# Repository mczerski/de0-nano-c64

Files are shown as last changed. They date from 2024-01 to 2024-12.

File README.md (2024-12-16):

# DE0-Nano expansion board for Commodore 64

This board adds necessary interfaces for Commodore 64 implementation from [this](https://github.com/mczerski/c64_DeMiSTify) project.

# Photos

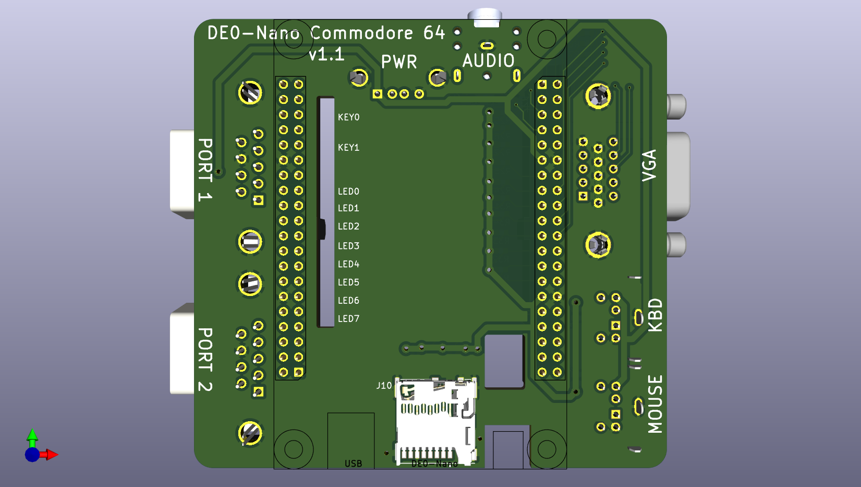
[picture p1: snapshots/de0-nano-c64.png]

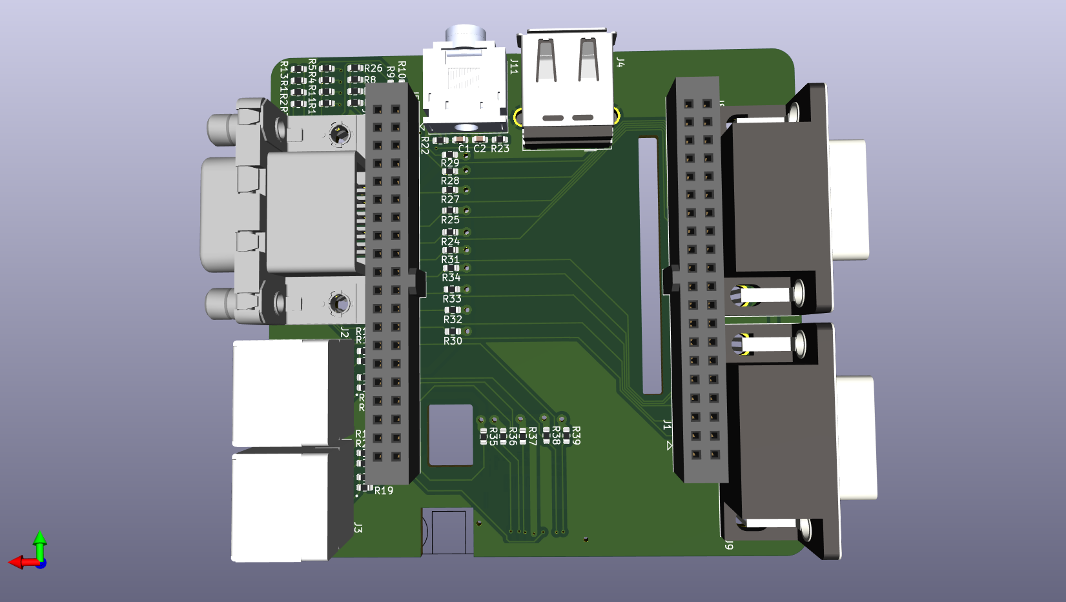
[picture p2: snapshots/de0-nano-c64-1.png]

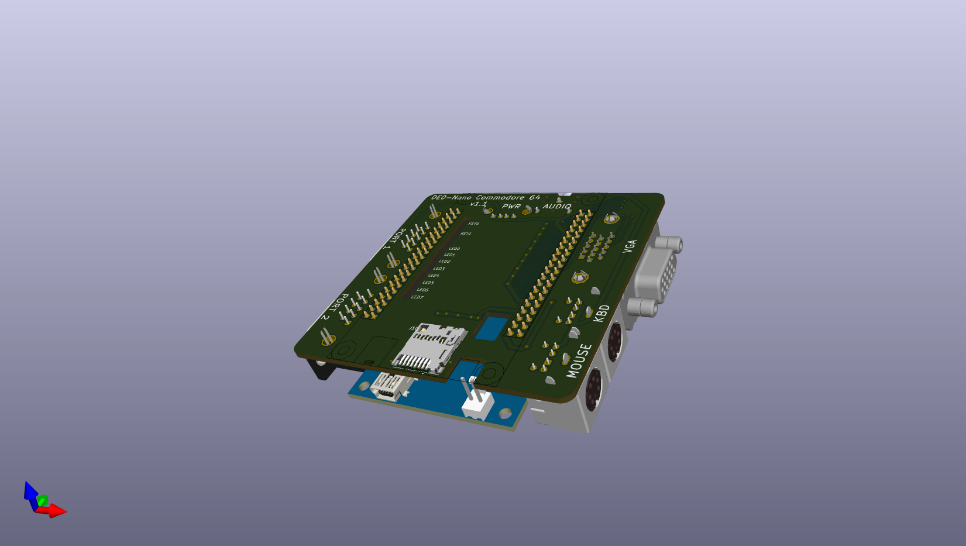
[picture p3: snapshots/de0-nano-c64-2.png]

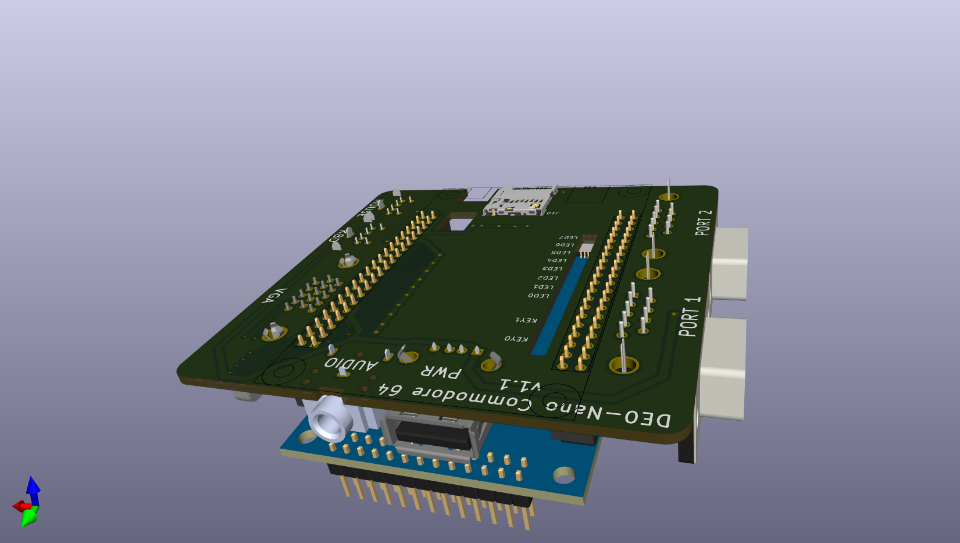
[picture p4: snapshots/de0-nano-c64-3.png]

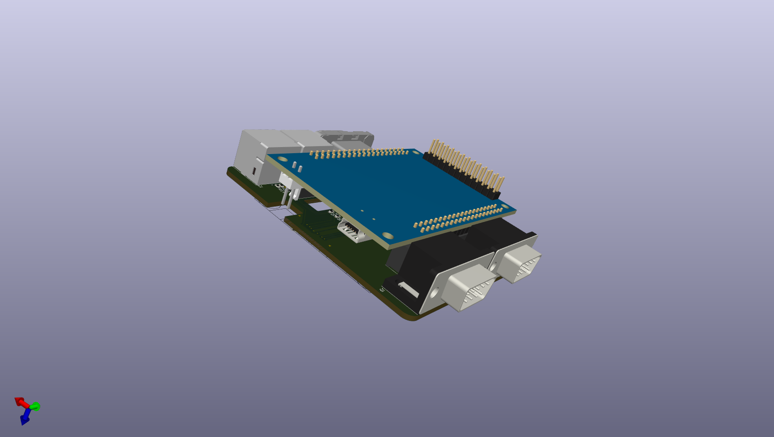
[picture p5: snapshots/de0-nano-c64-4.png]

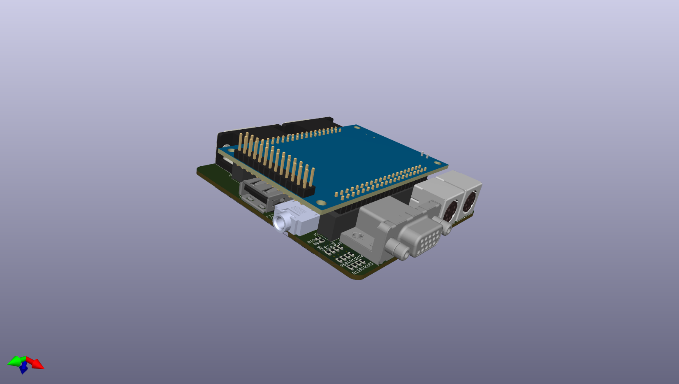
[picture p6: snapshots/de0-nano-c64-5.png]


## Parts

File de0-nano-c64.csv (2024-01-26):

Id | Oznaczenie | Footprint | Liczba | Oznaczenie | Dostawca i numer artykułu
1 | J10 | MOLEX_503398-1892 | 1 | SD_Card
2 | J6 | AMPHENOL_ICD15S13E4GV00LF | 1 | VGA
3 | C1,C2 | C_0603_1608Metric | 2 | 10n
4 | R1,R7,R11 | R_0603_1608Metric | 3 | 1k
5 | R2,R4,R8 | R_0603_1608Metric | 3 | 2k
6 | R3,R5,R26 | R_0603_1608Metric | 3 | 3.9K
7 | R6,R12,R13 | R_0603_1608Metric | 3 | 510
8 | R9,R10 | R_0603_1608Metric | 2 | 47
9 | R14,R15,R20,R21 | R_0603_1608Metric | 4 | 2K
10 | R16,R17,R18,R19 | R_0603_1608Metric | 4 | 120
11 | R22,R23 | R_0603_1608Metric | 2 | 4.7k
12 | R24,R25,R27,R28,R30,R31,R37,R32,R29,R34,R38,R35,R36,R33,R39 | R_0603_1608Metric | 15 | 10k
13 | J2 | CUI_MD-60S | 1 | PS2_0
14 | J1 | PinSocket_2x20_P2.54mm_Polarized_Vertical | 1 | GPIO_0
15 | J3 | CUI_MD-60S | 1 | PS2_1
16 | J5 | PinSocket_2x20_P2.54mm_Polarized_Vertical | 1 | GPIO_1
17 | J8 | DSUB-9_Male_Horizontal_P2.77x2.84mm_EdgePinOffset7.70mm_Housed_MountingHolesOffset9.12mm | 1 | JOYSTICK_1
18 | J11 | Jack_3.5mm_CUI_SJ1-3523N_Horizontal | 1 | AUDIO
19 | J9 | DSUB-9_Male_Horizontal_P2.77x2.84mm_EdgePinOffset7.70mm_Housed_MountingHolesOffset9.12mm | 1 | JOYSTICK_2

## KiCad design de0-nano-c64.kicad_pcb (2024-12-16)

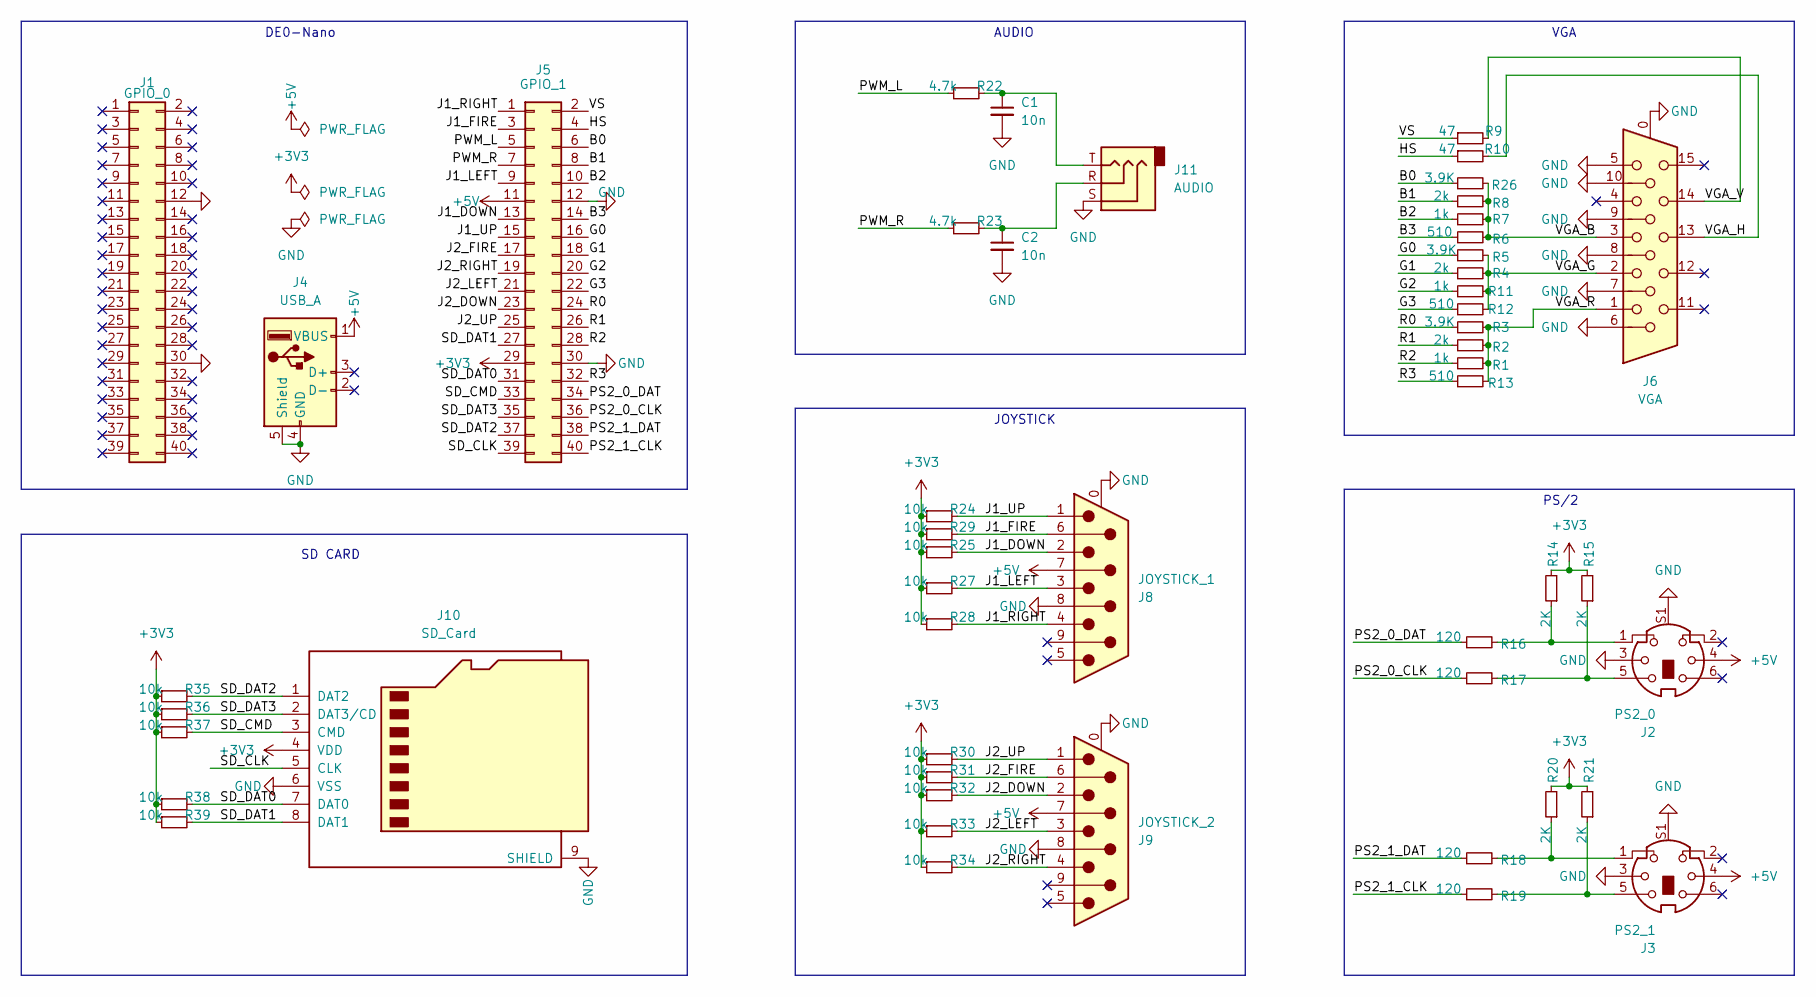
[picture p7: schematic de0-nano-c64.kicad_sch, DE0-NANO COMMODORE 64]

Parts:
C1, C2: 10n; C_0603_1608Metric
J1: GPIO_0; PinSocket_2x20_P2.54mm_Polarized_Vertical
J2: PS2_0; CUI_MD-60S
J3: PS2_1; CUI_MD-60S
J4: USB_A; USB_A_Molex_67643_Horizontal
J5: GPIO_1; PinSocket_2x20_P2.54mm_Polarized_Vertical
J6: VGA; AMPHENOL_ICD15S13E4GV00LF
J8: JOYSTICK_1; DSUB-9_Male_Horizontal_P2.77x2.84mm_EdgePinOffset7.70mm_Hou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
J9: JOYSTICK_2; DSUB-9_Male_Horizontal_P2.77x2.84mm_EdgePinOffset7.70mm_Hou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
J10: SD_Card; MOLEX_503398-1892
J11: AUDIO; Jack_3.5mm_CUI_SJ1-3523N_Horizontal
R1, R7, R11: 1k; R_0603_1608Metric
R2, R4, R8: 2k; R_0603_1608Metric
R3, R5, R26: 3.9K; R_0603_1608Metric
R6, R12, R13: 510; R_0603_1608Metric
R9, R10: 47; R_0603_1608Metric
R14, R15, R20, R21: 2K; R_0603_1608Metric
R16, R17, R18, R19: 120; R_0603_1608Metric
R22, R23: 4.7k; R_0603_1608Metric
R24, R25, R27, R28, R29, R30, R31, R32, R33, R34, R35, R36, R37, R38, R39: 10k; R_0603_1608Metric

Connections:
+3V3: J5.29, J10.4 (VDD), R14.2, R15.2, R20.2, R21.2, R24.1, R25.1, R27.1, R28.1, R29.1, R30.1, R31.1, R32.1, R33.1, R34.1, R35.1, R36.1, R37.1, R38.1, R39.1
+5V: J2.4, J3.4, J4.1 (VBUS), J5.11, J8.7, J9.7
/B0: J5.6, R26.1
/B1: J5.8, R8.1
/B2: J5.10, R7.1
/B3: J5.14, R6.1
/G0: J5.16, R5.1
/G1: J5.18, R4.1
/G2: J5.20, R11.1
/G3: J5.22, R12.1
/HS: J5.4, R10.1
/J1_DOWN: J5.13, J8.2, R25.2
/J1_FIRE: J5.3, J8.6, R29.2
/J1_LEFT: J5.9, J8.3, R27.2
/J1_RIGHT: J5.1, J8.4, R28.2
/J1_UP: J5.15, J8.1, R24.2
/J2_DOWN: J5.23, J9.2, R32.2
/J2_FIRE: J5.17, J9.6, R31.2
/J2_LEFT: J5.21, J9.3, R33.2
/J2_RIGHT: J5.19, J9.4, R34.2
/J2_UP: J5.25, J9.1, R30.2
/PS2_0_CLK: J5.36, R17.1
/PS2_0_DAT: J5.34, R16.1
/PS2_1_CLK: J5.40, R19.1
/PS2_1_DAT: J5.38, R18.1
/PWM_L: J5.5, R22.1
/PWM_R: J5.7, R23.1
/R0: J5.24, R3.1
/R1: J5.26, R2.1
/R2: J5.28, R1.1
/R3: J5.32, R13.1
/SD_CLK: J5.39, J10.5 (CLK)
/SD_CMD: J5.33, J10.3 (CMD), R37.2
/SD_DAT0: J5.31, J10.7 (DAT0), R38.2
/SD_DAT1: J5.27, J10.8 (DAT1), R39.2
/SD_DAT2: J5.37, J10.1 (DAT2), R35.2
/SD_DAT3: J5.35, J10.2 (DAT3/CD), R36.2
/VGA_B: J6.3, R6.2, R7.2, R8.2, R26.2
/VGA_G: J6.2, R4.2, R5.2, R11.2, R12.2
/VGA_H: J6.13, R10.2
/VGA_R: J6.1, R1.2, R2.2, R3.2, R13.2
/VGA_V: J6.14, R9.2
/VS: J5.2, R9.1
GND: C1.2, C2.2, J1.12, J1.30, J2.3, J2.S1, J3.3, J3.S1, J4.4 (GND), J4.5 (Shield), J5.12, J5.30, J6.0, J6.5, J6.6, J6.7, J6.8, J6.9, J6.10, J8.0 (PAD), J8.8, J9.0 (PAD), J9.8, J10.6 (VSS), J10.9 (SHIELD), J11.S
unnamed: C1.1, J11.T, R22.2
unnamed: C2.1, J11.R, R23.2
unnamed: J2.1, R14.1, R16.2
unnamed: J2.5, R15.1, R17.2
unnamed: J3.1, R18.2, R20.1
unnamed: J3.5, R19.2, R21.1

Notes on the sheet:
VGA
JOYSTICK
SD CARD
PS/2
DE0-Nano
AUDIO

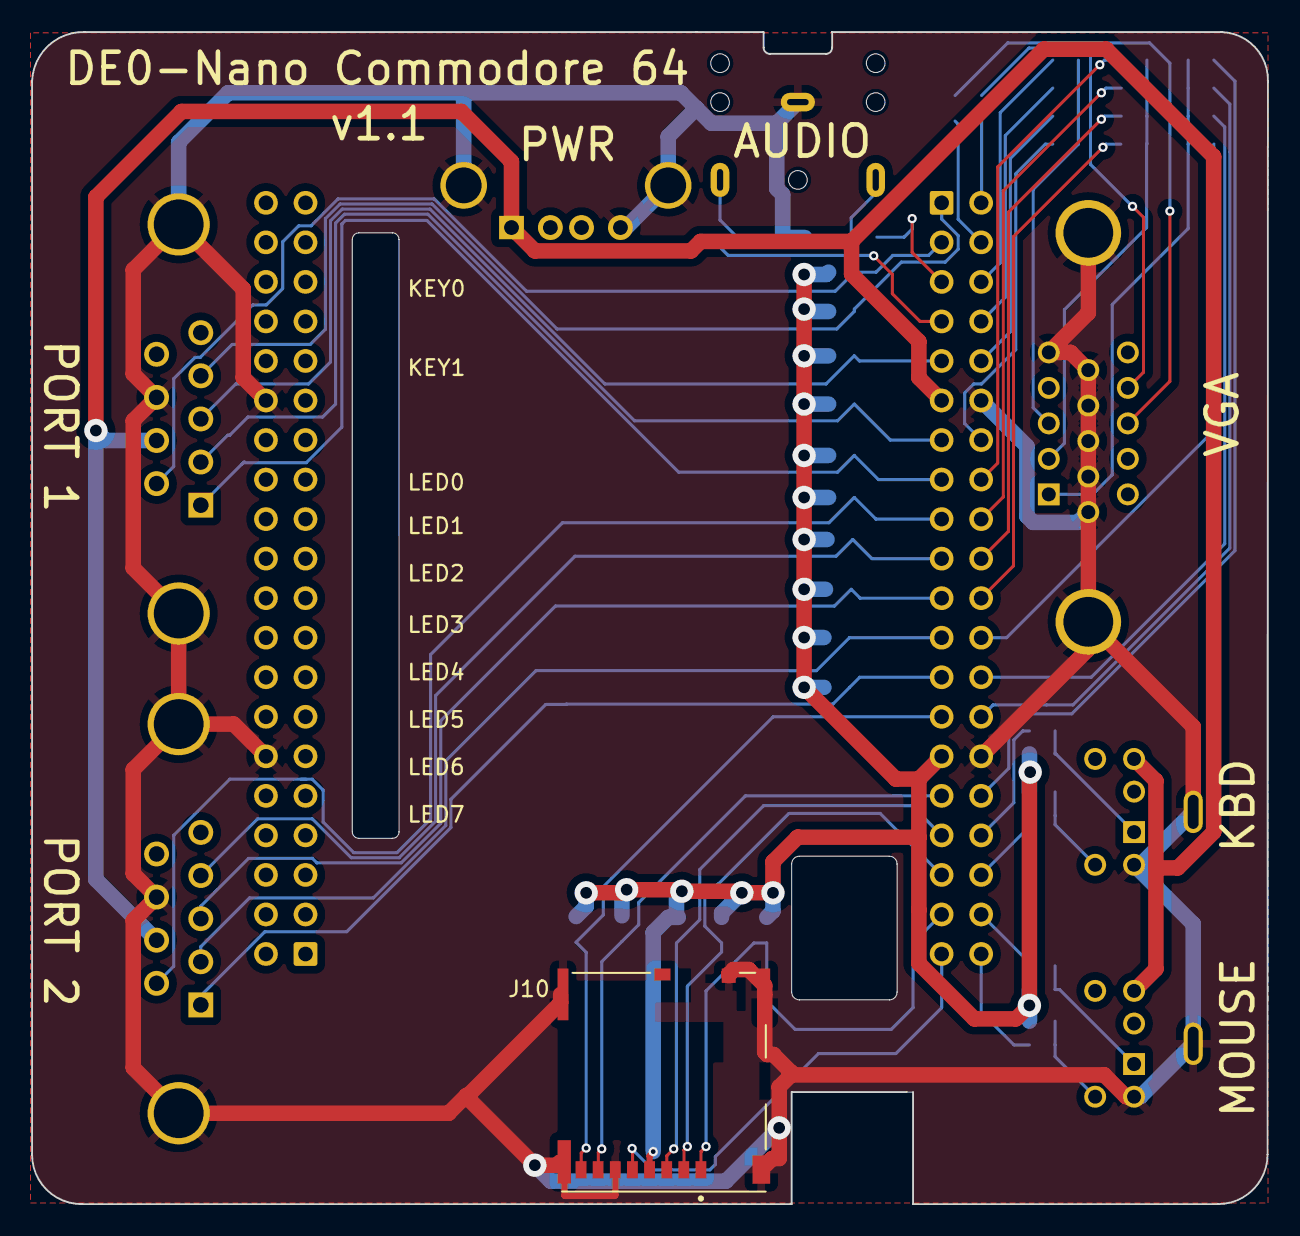
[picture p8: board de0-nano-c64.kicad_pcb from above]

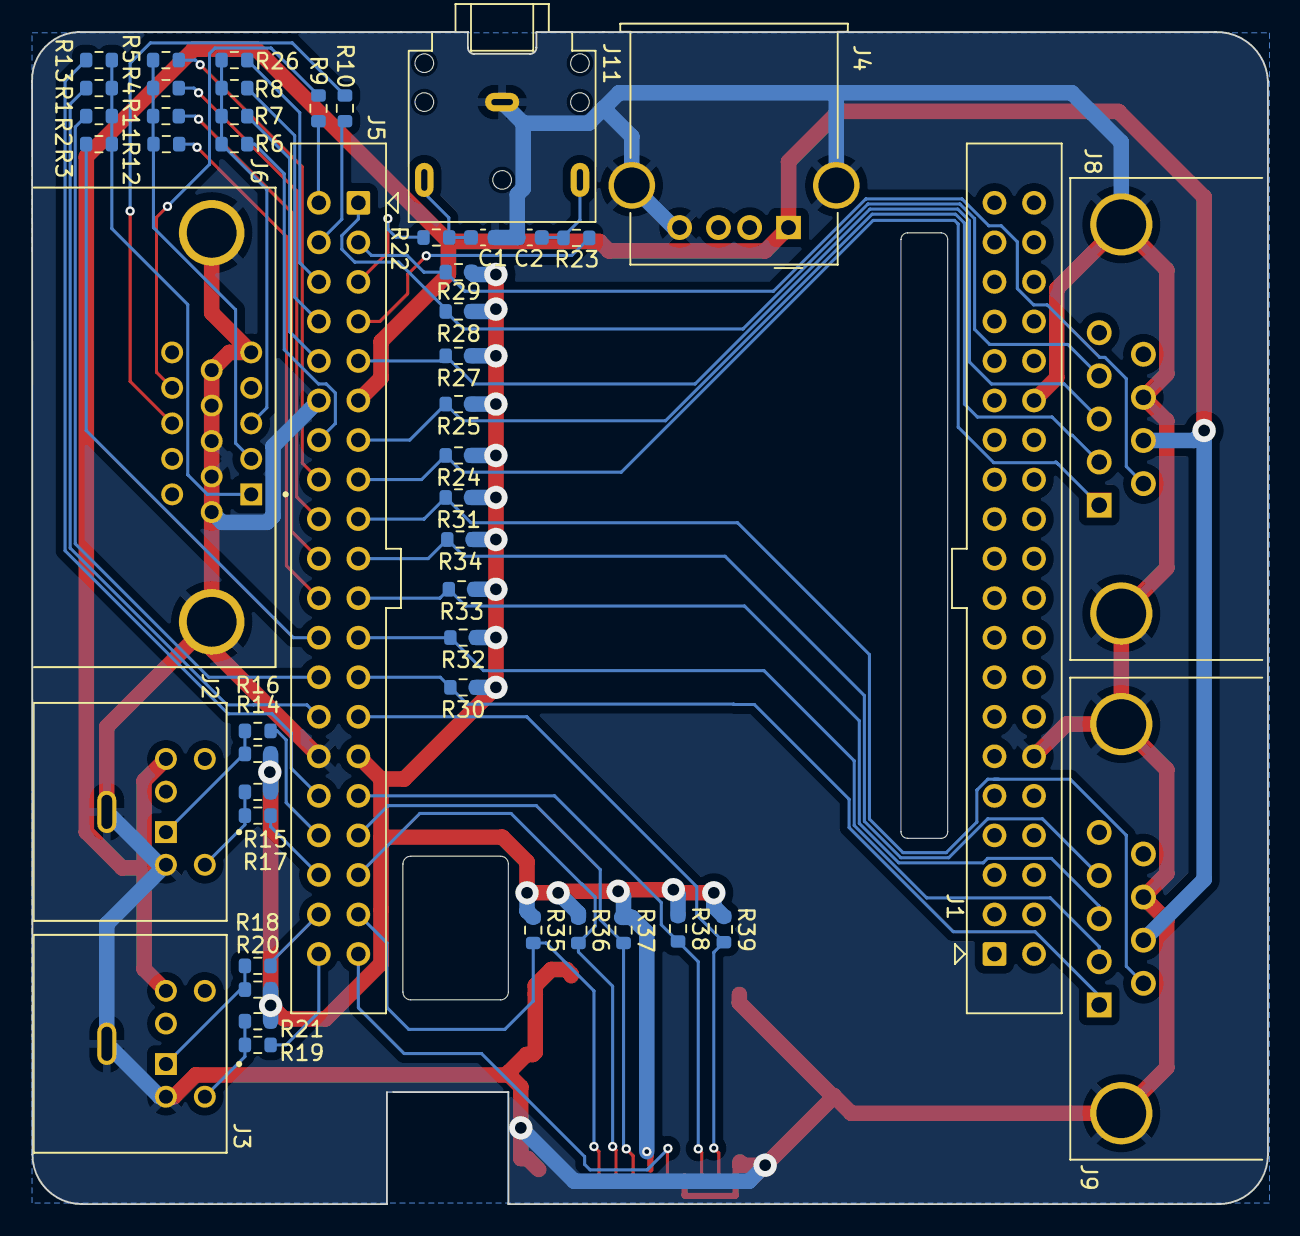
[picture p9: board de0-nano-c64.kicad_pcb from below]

Board: 2 copper layers, 79.4 x 75.3 mm, 52 parts (50 on the bottom side), 50 nets.

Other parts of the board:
DE0-Nano: DE0-Nano_bare

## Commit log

2024-01-10 version 1.0
    initial version
    ---------
    [de0-nano-c64.kicad_pcb, de0-nano-c64.kicad_sch]
2024-01-10 set gerber export settings for jlcpcb
    [de0-nano-c64.kicad_pcb]
2024-01-26 reorder some pins due to input only problem
    audio PWM_L/R were assigne to input only pins
    [de0-nano-c64.csv, de0-nano-c64.kicad_pcb, de0-nano-c64.kicad_sch]
2024-12-16 update to kicad 8.0
    [de0-nano-c64.kicad_pcb, de0-nano-c64.kicad_sch]
2024-12-16 add USB socket for power + add whole cut for dip switches
    [de0-nano-c64.kicad_pcb, de0-nano-c64.kicad_sch]
2024-12-16 update snapshots
    [de0-nano-c64.kicad_pcb]
